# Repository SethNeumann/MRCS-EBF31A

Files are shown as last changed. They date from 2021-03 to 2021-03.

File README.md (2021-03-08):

# REPO NAME: MRCS-EBF31A
## License: Creative Commons Attribution-NonCommercial-ShareAlike

The Electronic Battery Feed 31A provides power and off hook detection for a telephone talk circuit suitable for a Model Railroad dispatchers’ line. This is one of the circuits described in the New Operations SIG Book, A Compendium of Model Railroad Operations, Chapter 9.

EBF31A:

    Operates on 24 volts regulated DC, draws about 100 ma
    Supports at least 4 phones off hook at once, suitable for reading and copying orders on a TT&TO railroad
    Has a double-pole, double throw relay rated at 2A, with screw terminals for control of auxiliary circuits when off hook
    Has an LED "off hook" indicator
    Has an RJ11 jack and screw terminals for the phone line
    Has a 2.1mm center positive jack and screw terminals for power (supplies available from Jameco, Radio Shack, Amazon)
    Has a line level isolated monitor output on a stereo 3.5 mm audio jack
    snaps into the same 2.75" DIN rail that MRCS cpNodes and IOX16/32 expanders use

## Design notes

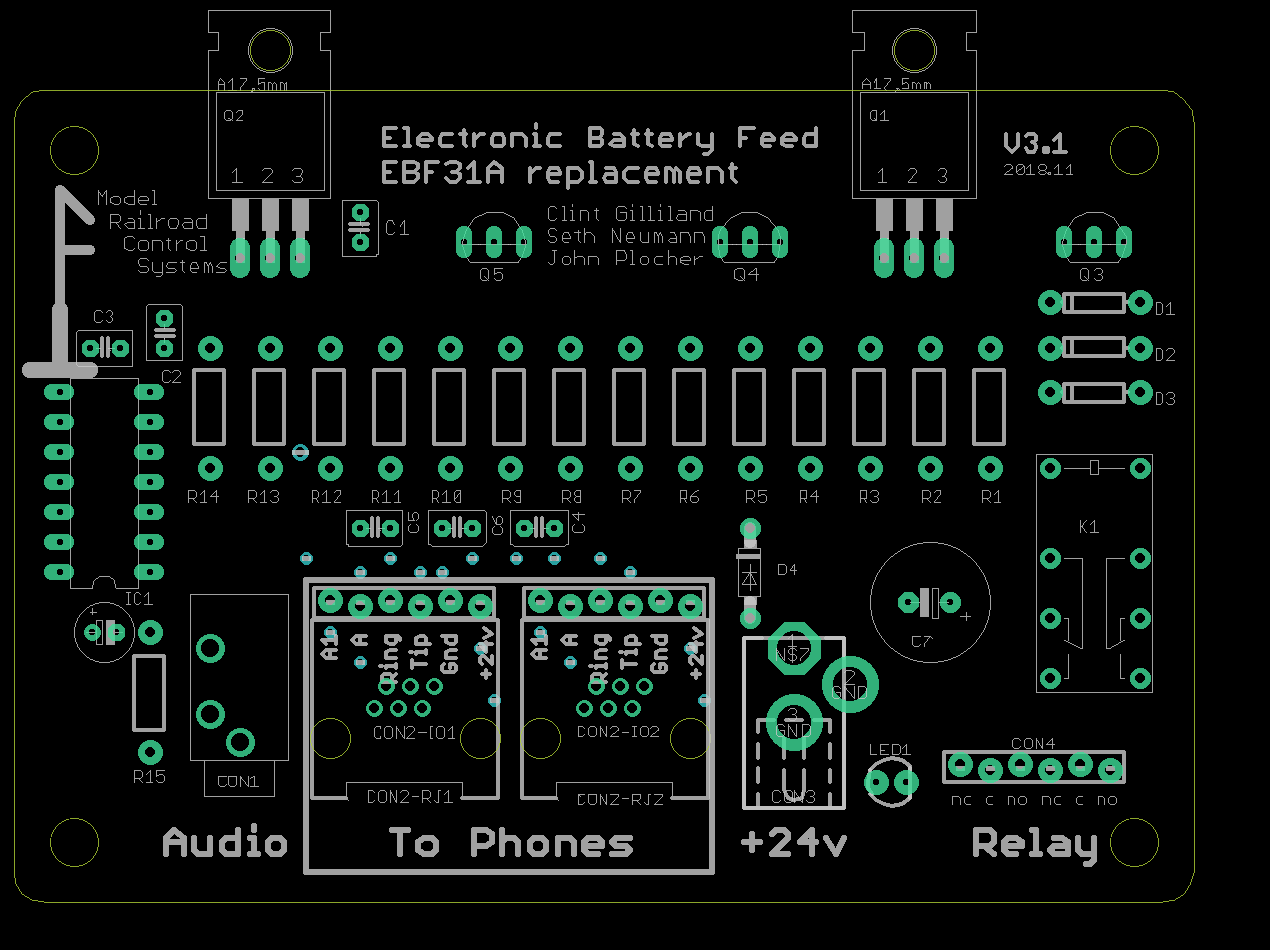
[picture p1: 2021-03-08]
EBF31A_V31.png

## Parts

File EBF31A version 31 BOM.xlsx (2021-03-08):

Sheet: Full BOM
Qty | Value | Device | Package | Parts | Description | Jameco | Digikey | Futurlec | Banggood/eBay | J$ | D$ | F$ | B$ | J Extd | D extd | F Extd | B Extd
1 |  | CONNECTOR-RJ25-43860-2-MOLEX | RJ25-INVERTED | CON2-RJ1, CON2-RJ2 | AMP connector |  | WM-5431-ND |  |  |  | 0.86 |  |  | $0.00 | $0.86 | $0.00 | $0.00
2 |  | M06FEMALE_LOCK | 1X06_FEMALE_LOCK.010 | CON2-IO1, CON2-IO2, CON4 | Header 6 |  |  |  | E-Salon | $0.60 |  |  |  | $1.20 | $0.00 | $0.00 | $0.00
1 | .01uF Cer | C-US025-030X050 | C025-030X050 | C1, DO NOT STUFF C6 | CAPACITOR, American symbol | 25507 |  |  |  | $0.19 |  |  |  | $0.19 | $0.00 | $0.00 | $0.00
4 | 0.1uF | C-US025-030X050 | C025-030X050 | C2, C3, C4, C5 | CAPACITOR, American symbol | 25523 |  |  |  | $0.19 |  |  |  | $0.76 | $0.00 | $0.00 | $0.00
4 | 100K | RESISTORPTH-1/4W | AXIAL-0.4 | R9, R10, R11, R12 | Resistor | 691340 |  |  |  | $0.02 |  |  |  | $0.08 | $0.00 | $0.00 | $0.00
1 | 100uF @ 50V | CPOL-USE3.5-10 | E3,5-10 | C7 | POLARIZED CAPACITOR, American symbol | 29962 |  |  |  | $0.10 |  |  |  | $0.10 | $0.00 | $0.00 | $0.00
5 | 10K | RESISTORPTH-1/4W | AXIAL-0.4 | R1, R4, R5, R6, R13 | Resistor | 691104 |  |  |  | $0.02 |  |  |  | $0.10 | $0.00 | $0.00 | $0.00
1 | 1N4002 | DIODE1N4001 | DIODE-1N4148 | D3 | Diode | 35975 |  |  |  | $0.05 |  |  |  | $0.05 | $0.00 | $0.00 | $0.00
2 | 1N4148 | DIODE1N4148 | DIODE-1N4148 | D1, D2 | Diode | 36038 |  |  |  | $0.04 |  |  |  | $0.08 | $0.00 | $0.00 | $0.00
1 | 1N5819-B | 1N5819-B | DO41-7.6 | D4 | 1.0A SCHOTTKY BARRIER RECTIFIER | 177965 |  |  |  | $0.19 |  |  |  | $0.19 | $0.00 | $0.00 | $0.00
1 | 2.2uF @ 50V | CPOL-USE2-5 | E2-5 | C8 | POLARIZED CAPACITOR, American symbol | 93731 |  |  |  | $0.09 |  |  |  | $0.09 | $0.00 | $0.00 | $0.00
1 | 22R | RESISTORPTH-1/4W | AXIAL-0.4 | R3 | Resistor | 690460 |  |  |  | $0.02 |  |  |  | $0.02 | $0.00 | $0.00 | $0.00
3 | 2K2 | RESISTORPTH-1/4W | AXIAL-0.4 | R2, R7, R8 | Resistor | 690945 |  |  |  | $0.02 |  |  |  | $0.06 | $0.00 | $0.00 | $0.00
3 | 2N4401 | 2N4401/2N3904 | TO92-EBC | Q3, Q4, Q5 | NPN Transistror | 783498 |  |  |  | $0.05 |  |  |  | $0.15 | $0.00 | $0.00 | $0.00
1 | 33R | RESISTORPTH-1/4W | AXIAL-0.4 | R14 | Resistor | 690507 |  |  |  | $0.02 |  |  |  | $0.02 | $0.00 | $0.00 | $0.00
1 | 680 | RESISTORPTH-1/4W | AXIAL-0.4 | R15 | Resistor | 690822 |  |  |  | $0.02 |  |  |  | $0.02 | $0.00 | $0.00 | $0.00
1 | BOARD | BOARD69X100MRCS | BOARD-DINRAIL-2.71IN-MRCS | U$1 |  |  |  |  | Seeed |  |  |  | $1.03 | $0.00 | $0.00 | $0.00 | $1.03
1 | G5V-2-24V | G5V-2 | G5V-2 | K1 | OMRON PCB Relay |  |  |  |  |  |  | $1.12 |  | $0.00 | $0.00 | $1.12 | $0.00
1 | Jameco 101187-RA | CONNECTOR-DC-POWER-RA | DCJ0202 | CON3 | DC POWER JACK | 101187 |  |  |  | $0.69 |  |  |  | $0.69 | $0.00 | $0.00 | $0.00
1 | LM324N | LM324N | DIL14 | IC1 | OP AMP | 23683 |  |  |  | $0.17 |  |  |  | $0.17 | $0.00 | $0.00 | $0.00
1 | Off Hook | LED3MM | LED3MM | LED1 | LEDs |  |  |  | kits |  |  |  | $0.01 | $0.00 | $0.00 | $0.00 | $0.01
1 | RS 2168149 | CONNECTOR-AUDIO3.5MM-ADAMTECH | AUDIO-JACK-3.5MM_STEREO | CON1 | 3.5mm Audio Jack | 2168149 |  |  |  | $0.99 |  |  |  | $0.99 | $0.00 | $0.00 | $0.00
1 | TIP31A | TIP31C | TO220 | Q1 | NPN Transistor | 33048 |  |  |  | $0.35 |  |  |  | $0.35 | $0.00 | $0.00 | $0.00
1 | TIP32A | TIP32C | TO220 | Q2 | PNP Transistor | 181841 |  |  |  | $0.35 |  |  |  | $0.35 | $0.00 | $0.00 | $0.00
1 |  | 14 pin DIP Socket | 14 pin DIP | IC1S | 14 pin DIP Socket | 112214 |  |  |  | $0.11 |  |  |  | $0.11 | $0.00 | $0.00 | $0.00
 |  |  |  |  |  |  |  |  |  |  |  |  |  | $5.77 | $0.86 | $1.12 | $1.04 | $8.79
 |  |  |  |  |  |  |  |  |  |  |  |  |  |  |  |  | 20% | $1.76
 |  |  |  |  |  |  |  |  |  |  |  |  |  |  | Parts subtotal |  |  | $10.55
 |  |  |  |  |  |  |  |  |  |  |  |  |  |  | Labor |  |  | 23.85
 |  |  |  |  |  |  |  |  |  |  |  |  |  |  |  |  | 20% | $4.77
 |  |  |  |  |  |  |  |  |  |  |  |  |  |  | Labor Subtotal |  |  | 28.62
 |  |  |  |  |  |  |  |  |  |  |  |  |  |  | Parts and Labor |  |  | $39.17
 |  |  |  |  |  |  |  |  |  |  |  |  |  |  | e-Commerce |  | 10% | $3.92
 |  |  |  |  |  |  |  |  |  |  |  |  |  |  | Grand Total |  |  | $43.08

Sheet: Build
Qty | Value | Device | Package | Parts | Description | Jameco | OC_NEWARK | Futurlec | Digikey | Banggood/eBay | MPN
1 |  | CONNECTOR-RJ25-43860-2-MOLEX | RJ25-INVERTED | CON2-RJ1, CON2-RJ2 | AMP connector
2 |  | M06FEMALE_LOCK | 1X06_FEMALE_LOCK.010 | CON2-IO1, CON2-IO2, CON4 | Header 6
1 | .01uF Cer | C-US025-030X050 | C025-030X050 | C1, DO NOT STUFF C6 | CAPACITOR, American symbol
4 | 0.1uF | C-US025-030X050 | C025-030X050 | C2, C3, C4, C5 | CAPACITOR, American symbol
4 | 100K | RESISTORPTH-1/4W | AXIAL-0.4 | R9, R10, R11, R12 | Resistor
1 | 100uF @ 50V | CPOL-USE3.5-10 | E3,5-10 | C7 | POLARIZED CAPACITOR, American symbol
5 | 10K | RESISTORPTH-1/4W | AXIAL-0.4 | R1, R4, R5, R6, R13 | Resistor
1 | 1N4002 | DIODE1N4148 | DIODE-1N4148 | D3 | Diode
2 | 1N4148 | DIODE1N4148 | DIODE-1N4148 | D1, D2 | Diode
1 | 1N5819-B | 1N5819-B | DO41-7.6 | D4 | 1.0A SCHOTTKY BARRIER RECTIFIER
1 | 2.2uF @ 50V | CPOL-USE2-5 | E2-5 | C8 | POLARIZED CAPACITOR, American symbol
1 | 22R | RESISTORPTH-1/4W | AXIAL-0.4 | R3 | Resistor
3 | 2K2 | RESISTORPTH-1/4W | AXIAL-0.4 | R2, R7, R8 | Resistor
3 | 2N4401 | 2N4401/2N3904 | TO92-EBC | Q3, Q4, Q5 | NPN Transistror
1 | 33R | RESISTORPTH-1/4W | AXIAL-0.4 | R14 | Resistor
1 | 680 | RESISTORPTH-1/4W | AXIAL-0.4 | R15 | Resistor
1 | BOARD | BOARD69X100MRCS | BOARD-DINRAIL-2.71IN-MRCS | U$1
1 | G5V-2-24V | G5V-2 | G5V-2 | K1 | OMRON PCB Relay |  | 78K5703
1 | Jameco 101187-RA | CONNECTOR-DC-POWER-RA | DCJ0202 | CON3 | DC POWER JACK
1 | LM324N | LM324N | DIL14 | IC1 | OP AMP
1 | Off Hook | LED3MM | LED3MM | LED1 | LEDs
1 | RS 2168149 | CONNECTOR-AUDIO3.5MM-ADAMTECH | AUDIO-JACK-3.5MM_STEREO | CON1 | 3.5mm Audio Jack
1 | TIP31A | TIP31C | TO220 | Q1 | NPN Transistor
1 | TIP32A | TIP30 | TO220 | Q2 | PNP Transistor
1 |  | 14 pin DIP Socket | 14 pin DIP | IC1S | 14 pin DIP Socket

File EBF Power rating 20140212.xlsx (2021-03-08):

Part Name | Type | Value | Units | Rating |  | Size | Eagle P/N |  | Jameco |  | Sparkfun/E-salon |  | Halted | Comment
 |  |  |  | computed | specified |  |  |  | p/n | $ in 10s | p/n | $ in 10s
C1 | Cap Elec | 100 | uF |  | 50V | 8 x 11 x 3.5mm |  | http://www.mouser.com/ProductDetail/Panasonic/ECA-1HM101/?qs=sGAEpiMZZMtZ1n0r9vR22YuzYhk2RkTK0vo2YUoLow4%3d | Part no. 29962 | 0.12 |  |  |  | need to check diameter and lead spacing against design
C2 | Cap Cer | 0.01 | uF |  | 50V |  |  | http://www.mouser.com/ProductDetail/Xicon/140-50Z5-103M-RC/?qs=sGAEpiMZZMt1mVBmZSXTPCB4s6x5SlOXBEu7ib2tazc%3d | Part no. 15229 | 0.10
C3 | Cap Elec | 2.20 | uF |  | 25V | 5 x 11 x 2mm |  |  | Part no. 158327 | 0.12 |  |  |  | need to check diameter and lead spacing against design
C4 | Cap Cer | 0.10 | uF |  | 50V |  |  | http://www.mouser.com/ProductDetail/Xicon/140-50U5-104M-RC/?qs=sGAEpiMZZMt1mVBmZSXTPPQUnq7ol7tGZljKIuTg6iI%3d | Part no. 151116 | 0.13 |  |  |  | mouser price is in 200s
C5 | Cap Cer | 0.10 | uF |  | 50V |  |  | http://www.mouser.com/ProductDetail/Xicon/140-50U5-104M-RC/?qs=sGAEpiMZZMt1mVBmZSXTPPQUnq7ol7tGZljKIuTg6iI%3d | Part no. 151116 | 0.13
C6 | Cap Cer | 0.10 | uF |  | 50V |  |  | http://www.mouser.com/ProductDetail/Xicon/140-50U5-104M-RC/?qs=sGAEpiMZZMt1mVBmZSXTPPQUnq7ol7tGZljKIuTg6iI%3d | Part no. 151116 | 0.13
C9 | Cap Cer | 0.10 | uF |  | 50V |  |  | http://www.mouser.com/ProductDetail/Xicon/140-50U5-104M-RC/?qs=sGAEpiMZZMt1mVBmZSXTPPQUnq7ol7tGZljKIuTg6iI%3d | Part no. 151116 | 0.13
D1 | Diode | 1N4148 |  |  |  |  |  | http://www.mouser.com/ProductDetail/Fairchild-Semiconductor/1N4148/?qs=sGAEpiMZZMudZehw8RjeZWbu6z6oTQTL | 36038 | 0.05 |  |  |  | have a bunch
D2 | Diode | 1N4148 |  |  |  |  |  | http://www.mouser.com/ProductDetail/Fairchild-Semiconductor/1N4148/?qs=sGAEpiMZZMudZehw8RjeZWbu6z6oTQTL | 36038 | 0.05
D3 | Diode | IN4002 |  |  |  |  |  | http://www.mouser.com/ProductDetail/Fairchild-Semiconductor/1N4001/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 | 76961 | 0.05 |  |  |  | in 10s
D4 | Diode | 1N5819 |  |  |  |  |  | http://www.mouser.com/ProductDetail/Fairchild-Semiconductor/1N5819/ | 177965 | 0.14 |  |  |  | have a bunch
J2 | Phone Jack | RJ11 |  |  |  |  |  |  |  |  | PRT-00132 | 1.13 |  | in the Sparkfun EagleCad library
JP2 | Audio Jack | 3.5mm |  |  |  |  |  |  |  |  | PRT-08032 | 1.50 |  | in the Sparkfun EagleCad library
JP3 | 0.100 Screw Term | 6 position |  |  |  |  |  |  |  |  |  | 1.30 |  | Electronics Salon
JP4 | 0.100 Screw Term | 4 position |  |  |  |  |  | http://www.mouser.com/ProductDetail/Xicon/299-100K-RC/?qs=sGAEpiMZZMu61qfTUdNhG81NIhcRRUJQ49frf6pyD3E%3d |  |  |  | 1.00 |  | Electronics Salon, I have a bunch
LED1 | LED | Red |  |  |  | 3mm |  | http://www.mouser.com/ProductDetail/Everlight/MV5064MP4B/ | 333851 | 0.12
Q10 | NPN | 2N4401 |  |  |  | TO92 |  | http://www.mouser.com/ProductDetail/Fairchild-Semiconductor/2N4401TA/ | 783498 | 0.06 |  |  |  | Subsitute for 2N2222A
Q11 | NPN | 2N4401 |  |  |  | TO92 |  | http://www.mouser.com/ProductDetail/Fairchild-Semiconductor/2N4401TA/ | 783498 | 0.06 |  |  |  | Subsitute for 2N2222A
Q7 | NPN | 2N4401 |  |  |  | TO92 |  | http://www.mouser.com/ProductDetail/Fairchild-Semiconductor/2N4401TA/ | 783498 | 0.06 |  |  |  | Subsitute for 2N2222A
Q8 | PNP | TIP32A |  |  |  | TO220 |  | http://www.mouser.com/ProductDetail/ON-Semiconductor/TIP32AG/ | 1959328 | 0.29
Q9 | NPN | TIP31A |  |  |  | TO220 |  | http://www.mouser.com/ProductDetail/Fairchild-Semiconductor/TIP31A/ | 1192850 | 0.29
Relay | Relay | OMRON G5v2-24 | 1152 ohms | DPDT |  |  |  | http://www.mouser.com/ProductDetail/Omron-Electronics/G5V-2-DC24/ | 2139049 | 1.95 |  |  |  | Jameco is HI version coil = 2880 ohms
R14 | Resistor | 10000 | ohms | 0.05 | 0.250 | 0.3 |  | http://www.mouser.com/ProductDetail/Xicon/299-10K-RC/?qs=sGAEpiMZZMu61qfTUdNhG6xwTrVwTvbzMFVIwePn7Hs%3d | 691104 | 0.10
R15 | Resistor | 33 | ohms | 0.03 | 0.250 | 0.3 |  |  | 691227 | 0.10 |  |  |  | Jameco in bags of 10 or 100: $ 0.10 ea for 10, $0.04 in 100s
R16 | Resistor | 10000 | ohms | 0.04 | 0.250 | 0.3 |  |  | 691104 | 0.10
R17 | Resistor | 10000 | ohms | 0.01 | 0.250 | 0.3 |  |  | 691104 | 0.10
R18 | Resistor | 27 | ohms | 0.05 | 0.250 | 0.3 |  |  | 691201 | 0.10
R2 | Resistor | 2200 | ohms | 0.22 | 0.250 | 0.4 |  | http://www.mouser.com/ProductDetail/Xicon/291-22K-RC/ | Part no. 690945 | 0.10 |  |  |  | have a bunch of 2.4 K x .25W on hand, for LED
R20 | Resistor | 10000 | ohms | 0.0004 | 0.250 | 0.3 |  |  | 691104 | 0.10
R21 | Resistor | 10000 | ohms | 0.01 | 0.250 | 0.3 |  |  | 691104 | 0.10
R22 | Resistor | 2200 | ohms | 1.636363636e-08 | 0.250 | 0.3 |  | http://www.mouser.com/ProductDetail/Xicon/299-22K-RC/?qs=sGAEpiMZZMu61qfTUdNhGzmcydQ1pJoanehw0NWTJkc%3d | 690945 | 0.10
R23 | Resistor | 2200 | ohms | 1.636363636e-08 | 0.250 | 0.3 |  | http://www.mouser.com/ProductDetail/Xicon/299-22K-RC/?qs=sGAEpiMZZMu61qfTUdNhGzmcydQ1pJoanehw0NWTJkc%3d | 690945 | 0.10
R3 | Resistor | 22 | ohms | 0.22 | 0.500 | 0.4 |  | http://www.mouser.com/ProductDetail/Xicon/291-33-RC/?qs=sGAEpiMZZMu61qfTUdNhG0PRcDhRwGd7HA5vz0k3Egc%3d | 661837 | 0.05 |  |  |  | in 100s @ Jameco, no 10s - try RS
R4 | Resistor | 680 | ohms |  | 0.250 | 0.3 |  |  | 690822 | 0.10 |  |  |  | in 100s, .10 in 10s
R5 | Resistor | 100000 | ohms |  | 0.250 | 0.3 |  | http://www.mouser.com/ProductDetail/Xicon/299-100K-RC/?qs=sGAEpiMZZMu61qfTUdNhG81NIhcRRUJQ49frf6pyD3E%3d | 691340 | 0.10
R6 | Resistor | 100000 | ohms |  | 0.250 | 0.3 |  |  | 691340 | 0.10
R7 | Resistor | 100000 | ohms |  | 0.250 | 0.3 |  |  | 691340 | 0.10
R8 | Resistor | 100000 | ohms |  | 0.250 | 0.3 |  |  | 691340 | 0.10
U1 | OP AMP | LM324N |  |  |  |  |  | http://www.mouser.com/ProductDetail/Texas-Instruments/LM324NE3/ | 23683 | 0.25
 |  |  |  |  |  |  |  |  |  | 5.78 |  | 4.93
 |  | 2N4401 |  |  |  |  |  | http://www.mouser.com/ProductDetail/Fairchild-Semiconductor/2N4401TA/ | 783498 | 0.06 |  |  |  | Subsitute for 2N2222A
Relay | OMRON G5v2-24 |  | 1152 ohms | DPDT |  |  |  | http://www.mouser.com/ProductDetail/Omron-Electronics/G5V-2-DC24/ | 2139049 | 1.95 |  |  |  | Using a 24V relay is same price and eliminates R 1. Jameco is HI version coil = 2880 ohms
Relay | OMRON G5v2-12 |  | 288 ohms | DPDT |  |  |  | http://www.mouser.com/ProductDetail/Omron-Electronics/G5V-2-DC12/ | 187258 | 2.95
R1 | Resistor | 270 | ohms | 0.43 | 0.500 | 0.5

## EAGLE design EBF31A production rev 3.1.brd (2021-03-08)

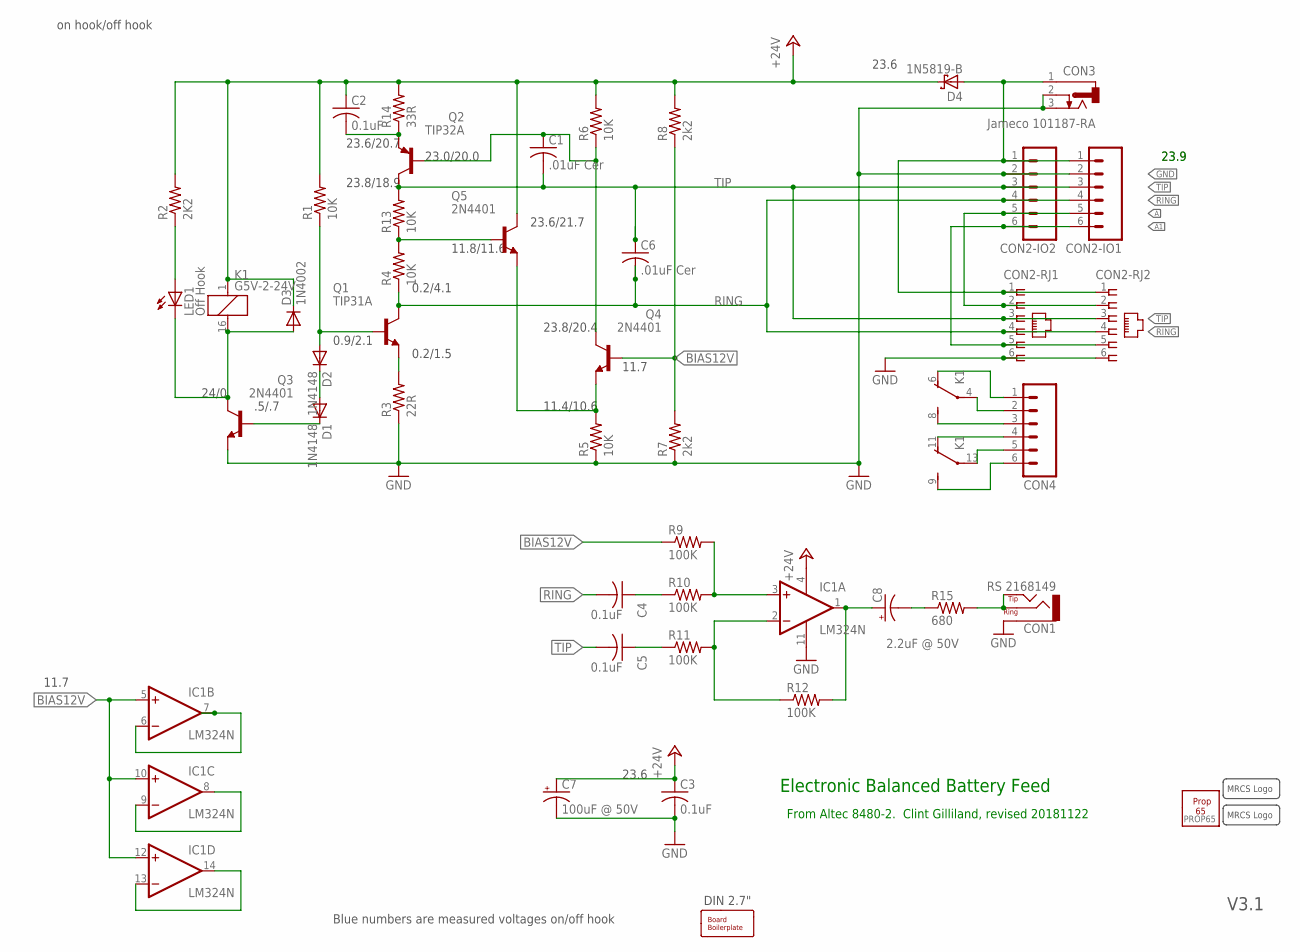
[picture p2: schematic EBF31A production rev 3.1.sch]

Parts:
C1, C6: .01uF Cer; C025-030X050
C2, C3, C4, C5: 0.1uF; C025-030X050
C7: 100uF @ 50V; E3,5-10
C8: 2.2uF @ 50V; E2-5
CON1: RS 2168149; AUDIO-JACK-3.5MM_STEREO
CON2-IO1, CON2-IO2, CON4: M06FEMALE_LOCK; 1X06_FEMALE_LOCK.010
CON2-RJ1, CON2-RJ2: CONNECTOR-RJ25-43860-2-MOLEX; RJ25-INVERTED
CON3: Jameco 101187-RA; DCJ0202
D1, D2: 1N4148; DIODE-1N4148
D3: 1N4002; DIODE-1N4148
D4: 1N5819-B; DO41-7.6
IC1: LM324N; DIL14
K1: G5V-2-24V; G5V-2
LED1: Off Hook; LED3MM
Q1: TIP31A; TO220
Q2: TIP32A; TO220
Q3, Q4, Q5: 2N4401; TO92-EBC
R1, R4, R5, R6, R13: 10K; AXIAL-0.4
R2: 2K2; AXIAL-0.4
R3: 22R; AXIAL-0.4
R7, R8: 2k2; AXIAL-0.4
R9, R10, R11, R12: 100K; AXIAL-0.4
R14: 33R; AXIAL-0.4
R15: 680; AXIAL-0.4
U$1: BOARD; BOARD-DINRAIL-2.71IN-MRCS
U$2, U$3: MRCS-LOGOBOT-LARGE; MRCS-LOGO
U$4: PROP65

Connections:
+24V: C2.1, C3.1, C7.+, D3.C, D4.C, IC1.4 (V+), K1.1, Q5.C, R1.P$2 (2), R2.P$2 (2), R6.P$2 (2), R8.P$2 (2), R14.P$2 (2)
A: CON2-IO1.5, CON2-IO2.5, CON2-RJ1.2, CON2-RJ2.2
A1: CON2-IO1.6, CON2-IO2.6, CON2-RJ1.5, CON2-RJ2.5
BIAS12V: IC1.5 (+IN), IC1.10 (+IN), IC1.12 (+IN), Q4.B, R7.P$2 (2), R8.P$1 (1), R9.P$1 (1)
GND: C3.2, C7.-, CON1.GND (SLEEVE), CON2-IO1.2, CON2-IO2.2, CON2-RJ1.6, CON2-RJ2.6, CON3.2, CON3.3, IC1.11 (V-), Q3.E, R3.P$1 (1), R5.P$1 (1), R7.P$1 (1)
unnamed: C2.2, Q2.3 (E), R14.P$1 (1)
unnamed: CON4.2, K1.4
unnamed: Q5.B, R4.P$2 (2), R13.P$1 (1)
unnamed: IC1.2 (-IN), R11.P$2 (2), R12.P$1 (1)
unnamed: Q1.3 (E), R3.P$2 (2)
unnamed: LED1.A, R2.P$1 (1)
unnamed: CON2-IO1.1, CON2-IO2.1, CON2-RJ1.1, CON2-RJ2.1, CON3.1, D4.A
unnamed: Q4.E, Q5.E, R5.P$2 (2)
unnamed: C1.1, Q2.1 (B), Q4.C, R6.P$1 (1)
unnamed: D1.C, Q3.B
unnamed: D1.A, D2.C
unnamed: D2.A, Q1.1 (B), R1.P$1 (1)
unnamed: D3.A, K1.16 (2), LED1.K (C), Q3.C
unnamed: IC1.13 (-IN), IC1.14 (OUT)
unnamed: CON4.6, K1.9 (S)
unnamed: CON4.1, K1.6 (O)
unnamed: CON4.3, K1.8 (S)
unnamed: C5.1, R11.P$1 (1)
unnamed: C8.+, IC1.1 (OUT), R12.P$2 (2)
unnamed: CON4.5, K1.13
unnamed: IC1.6 (-IN), IC1.7 (OUT)
unnamed: CON4.4, K1.11 (O)
unnamed: C8.-, R15.P$1 (1)
unnamed: CON1.RING, CON1.TIP, R15.P$2 (2)
unnamed: IC1.3 (+IN), R9.P$2 (2), R10.P$2 (2)
unnamed: C4.1, R10.P$1 (1)
unnamed: IC1.8 (OUT), IC1.9 (-IN)
RING: C4.2, C6.2, CON2-IO1.4, CON2-IO2.4, CON2-RJ1.4, CON2-RJ2.4, Q1.2 (C), R4.P$1 (1)
TIP: C1.2, C5.2, C6.1, CON2-IO1.3, CON2-IO2.3, CON2-RJ1.3, CON2-RJ2.3, Q2.2 (C), R13.P$2 (2)

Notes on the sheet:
Electronic Balanced Battery Feed
From Altec 8480-2. Clint Gilliland, revised 20181122
DIN 2.7"
V3.1
on hook/off hook
24/0
.5/.7
0.9/2.1
0.2/1.5
0.2/4.1
23.8/18.9
23.6/20.7
23.0/20.0
11.4/10.6
23.8/20.4
11.8/11.6
23.6/21.7
23.9
23.6
Blue numbers are measured voltages on/off hook
11.7

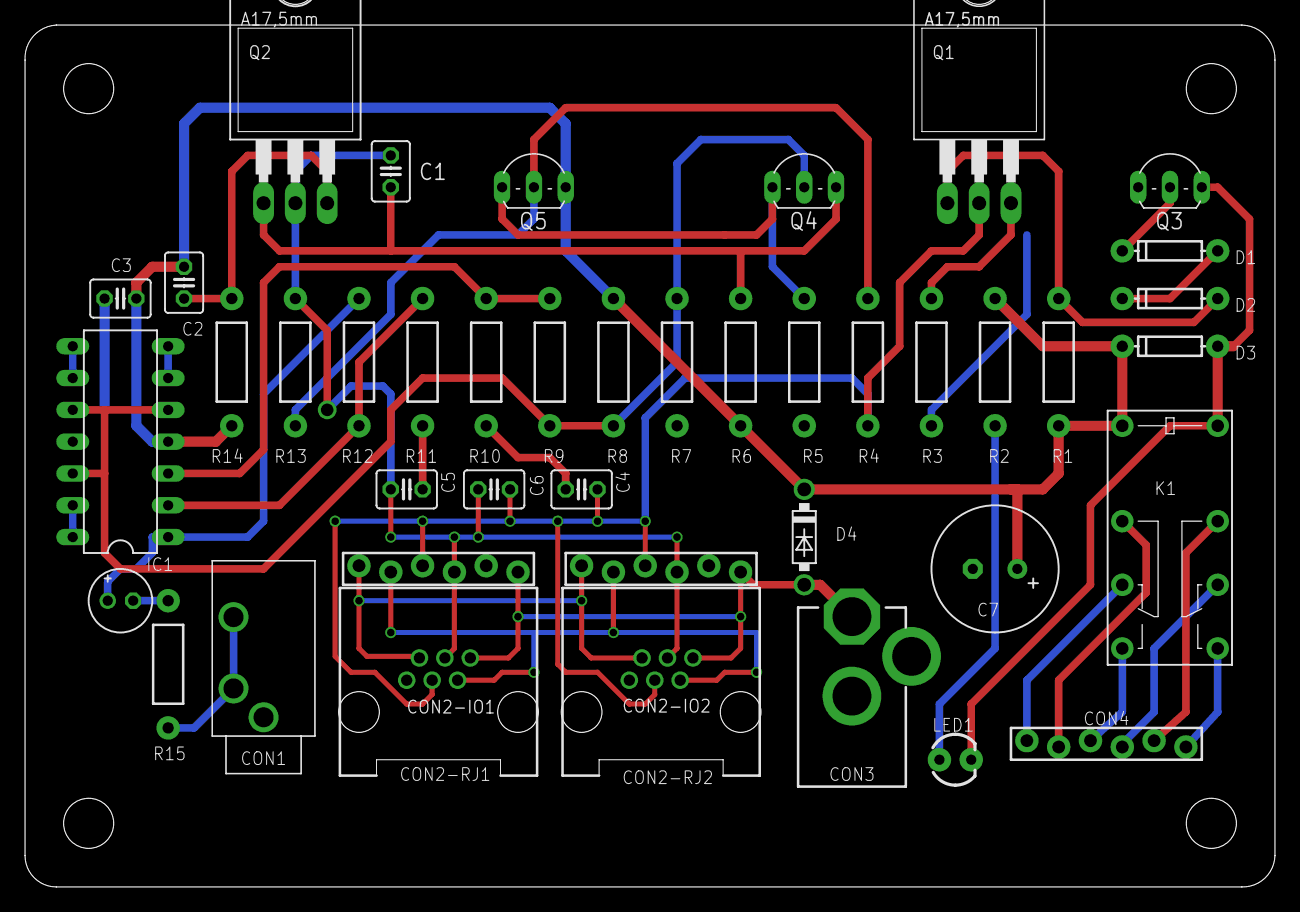
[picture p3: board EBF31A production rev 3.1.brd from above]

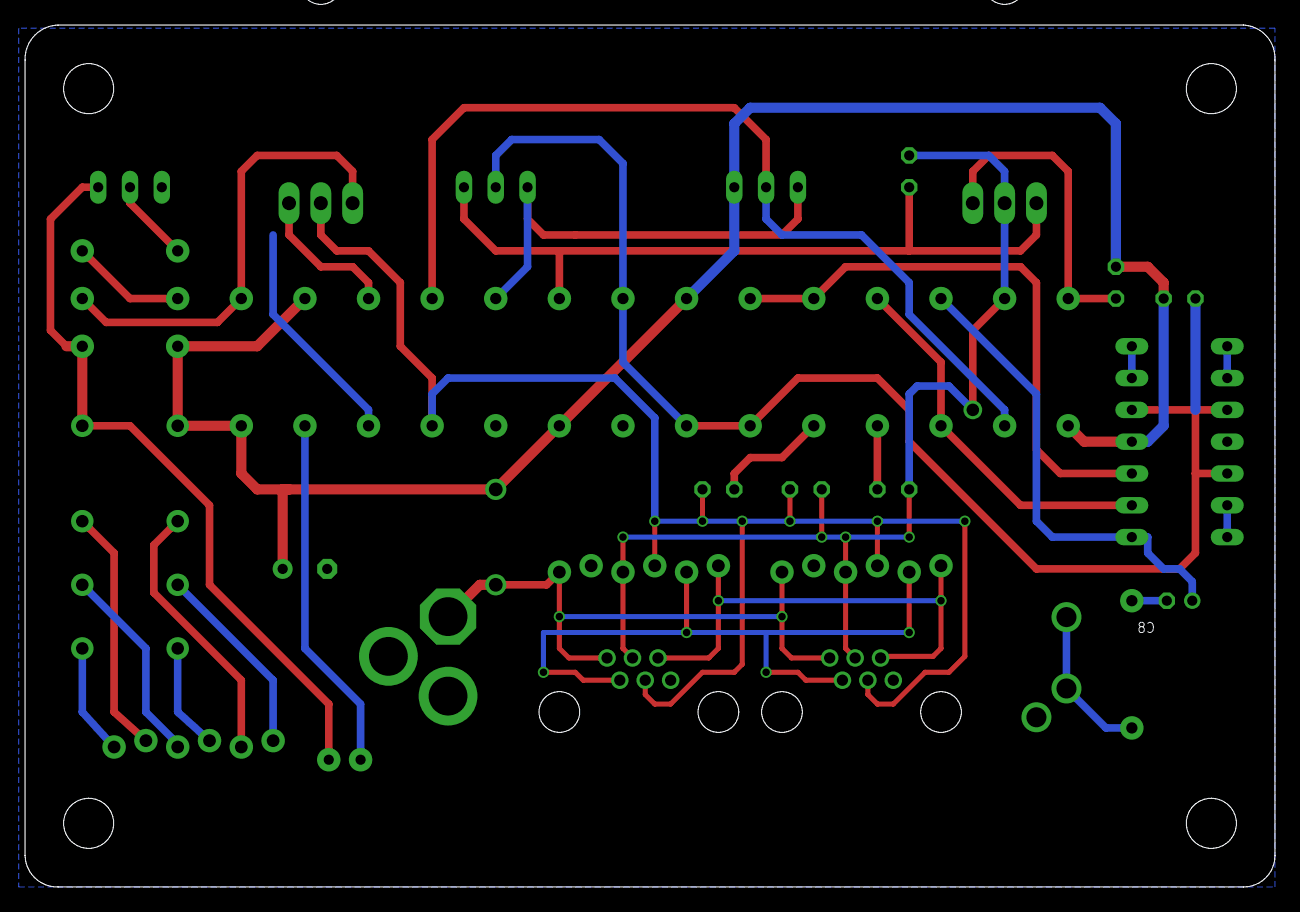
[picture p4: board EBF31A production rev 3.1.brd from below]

Board: 2 copper layers, 99.8 x 68.8 mm, 46 parts (2 on the bottom side), 34 nets.

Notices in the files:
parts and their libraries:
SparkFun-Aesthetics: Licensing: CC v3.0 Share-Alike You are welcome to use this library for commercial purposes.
